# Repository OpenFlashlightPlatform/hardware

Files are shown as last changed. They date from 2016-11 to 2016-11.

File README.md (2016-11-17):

# Blue Sun OFP

The Blue Sun Open Flashlight Platform is an open source (both hardware and software)
attempt at creating a software-defined ultra-reliable high-performance flashlight.

This project was inspired by the AvE Midnight Sun project, and is intended to match
with the mechanicals developed there, both physically and in spirit. To that end,
a core set of specifications were identified:

 0. The project must be fun. This rule can be applied to override any subsequent
    rule.
 1. The design must be skookum. If in doubt as to the actual definition of "skookum"
    just go balls to the wall and hope the result is sufficiently epic.
 2. The platform should be capable of driving a diverse range of COBs at up to
    160W (40V / 4A). Ensure that in every aspect of the circuit, rule 1 is
    strongly enforced, so that excursions beyond 160W are tolerated and the
    circuit can dynamically detect and react to overload.
 3. The driver should have fine-grained current-mode control of the COB.
 4. The platform should operate from a 3s LiPo battery, and be capable of charging it
    from a 12V source. Naturally, transients, noise and polarity inversions on this
    source must be tolerated. Furthermore, all best practices for LiPo operation
    must be followed including UVLO, cell balancing and temperature monitoring.
 5. The platform should be accessible and open source at every possible level.
    To that end, it should be compatible out-of-the box with an Arduino IDE
    and programmable without any non-free tools, software or licenses.
 6. The circuit must be implemented in the spirit of Rule 1. Everything must be
    resistant to temperature, humidity, vibration, ESD, overvoltage, cell imbalance,
    and short circuit. The circuit must continue to function after being shaken
    in a container of salty boiling water mixed with conductive metal powder.
 7. Every net in the circuit, including internal nets and power supply rails,
    must pass IEC 61000-4-2 (25kV) and IEC 61004-4 (40A) ESD resistance tests.
 8. The firmware itself, both in source form and compiled form, must adhere to
    rule 1. In particular, wherever possible (in that it does not contradict rule
    5), the firmware should be MISRA C:2012 compliant.
 9. Every aspect of the project must be well documented. If the primary maintainer
    were to become unavailable, the community ought to be able to pick up and
    continue.

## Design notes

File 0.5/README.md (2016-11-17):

# Version 0.5

This is a prototype iteration, that has no battery charging features. It is so that I can work on the hardware and firmware in parallel.

It should in theory work for up to 160W COBs. I'll be testing that at a later stage.

The BOM is also available as a google doc here: https://goo.gl/zxzSkw

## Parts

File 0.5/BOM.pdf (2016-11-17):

Nothing fancy passives, any brand will do
Designator | Type | Notes
C1, C15, C17 | 100nF 25V 0603 X7R
C28 | 10uF 25V 0805 X5R | The pad is 0603, my bad
C16, C18 | 1uF 25V 0603 X7R
C2 | 10uF 6V3 0603 X5R
C3, C5, C7, C9, C12, C13, C21, C22, C23, C25, C26, C30 | 100nF 6V3 0603 X7R
C4, C6, C8, C10, C11, C14, C24, C27, C29 | 1uF 6V3 0603 X7R
R1, R2 | 5k6 0603 1%
R4, R6 | 1k 0603 1%
R5 | 82k 0603 1%
R7 | 15k 0603 1%
R8, R9 | 1k8 0603 1%
R10, R11, R12, R13 | 100R 0603 1%
R14, R15, R16 | 10k 0603 1%

Specific parts
Designator | Type | Manufacturer | MFG part no | Digikey part no | Price/100 USD | Qty | Notes
C19, C20 | 1mF 80V 10mm cap | CDE | 381LX102M080H012 | 338-3690-ND | 1.7 | 2
D1, D8 | SOT23 Schottky | Fairchild | BAT54C | BAT54CFSTR-ND | 0.09 | 2
D4, D5, D6, D7 | TVS diode 3.3V | Semtech | UCLAMP3301H.TCT | UCLAMP3301HCT-ND | 0.48 | 4
D2 | Big SlimDPAK schottky | Vishay | V35PWM12-M3/I | V35PWM12-M3/IGITR-ND | 0.88 | 1
J1 | SMT USB micro | Amphenol | 10118192-0001LF | 609-4613-1-ND | 0.3 | 1
L1 | 10uH 21A inductor | Wurth | 74435581000 | 732-4235-2-ND | 6.6 | 1
Q1, Q2 | Power MOSFET | NXP | PSMN034-100BS,118 | 568-9702-2-ND | 0.71 | 2
Q3, Q4 | Signal MOSFET | NXP | 2N7002P,215 | 568-5818-1-ND | 0.07 | 2
U1 | MCU | Atmel | ATSAMD21G18A-AUT | ATSAMD21G18A-AUTCT-ND | 4.15 | 1
U2 | LDO | ST Micro | LD1117S33CTR | 497-1241-1-ND | 0.25 | 1
U3, U4 | MOSFET driver | Microchip | MCP1416T-E/OT | MCP1416T-E/OTTR-ND | 0.49 | 2
U5, U6, U7 | Temp sensor | TI | LM73CIMK-1/NOPB | LM73CIMK-1/NOPBCT-ND | 1.48 | 3
U8, U9, U10 | Steering / TVS | NXP | IP4220CZ6,125 | 568-3529-2-ND | 0.23 | 3
R3 | Shunt resistor 15mR | TE Connectivity | RLP73V3AR015FTDF | A109674CT-ND | 0.25 | 1
D3 | The COB 13 klm (!) | CREE | CXA3590-0000-000N00CD0E3 | CXA3590-0000-000N00CD0E3-ND | 37.18 | 1 | Any <40V <4A COB is ok

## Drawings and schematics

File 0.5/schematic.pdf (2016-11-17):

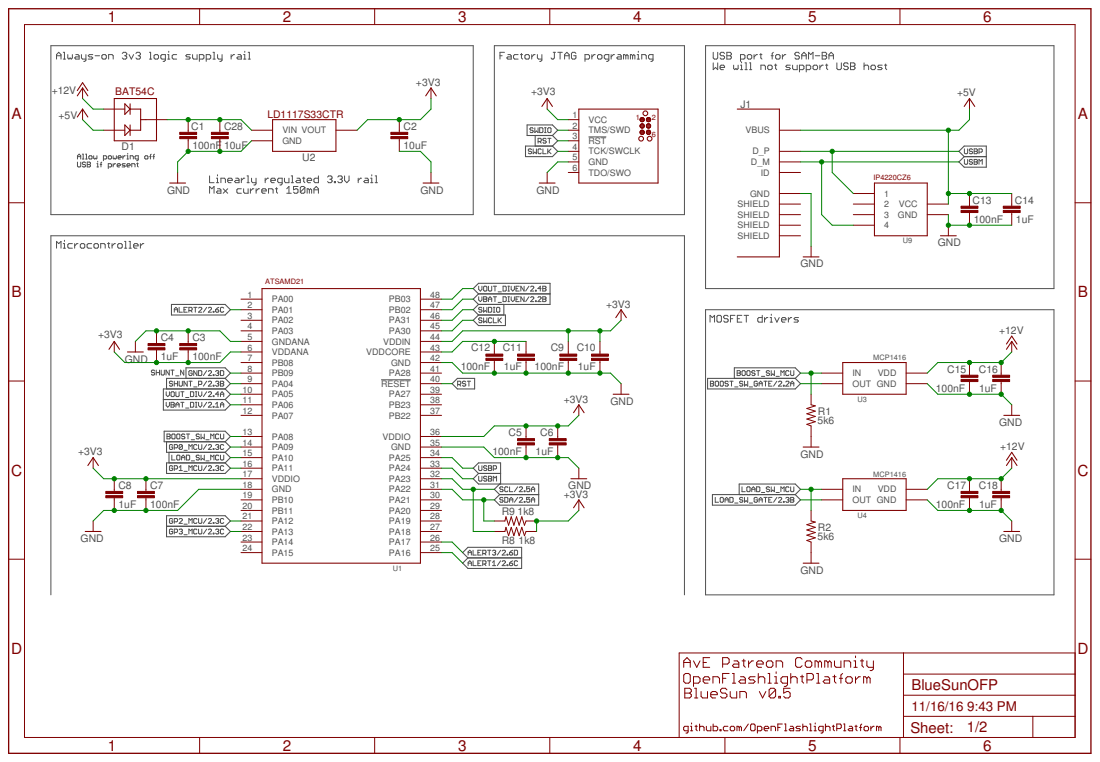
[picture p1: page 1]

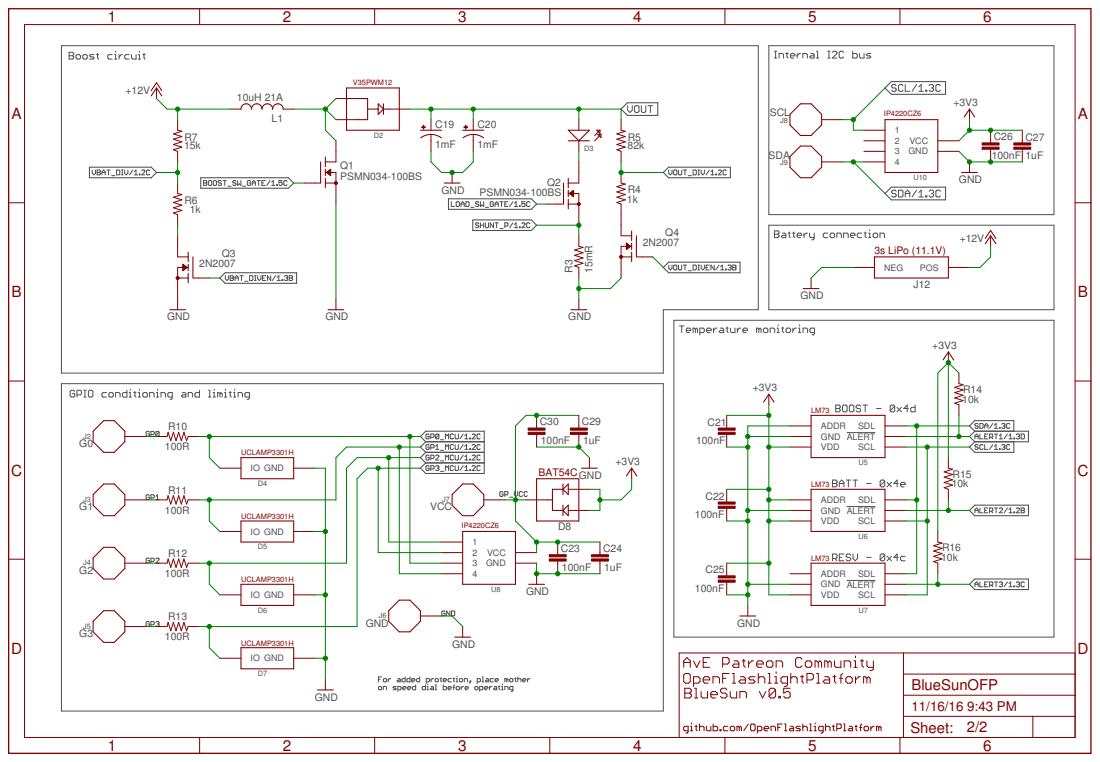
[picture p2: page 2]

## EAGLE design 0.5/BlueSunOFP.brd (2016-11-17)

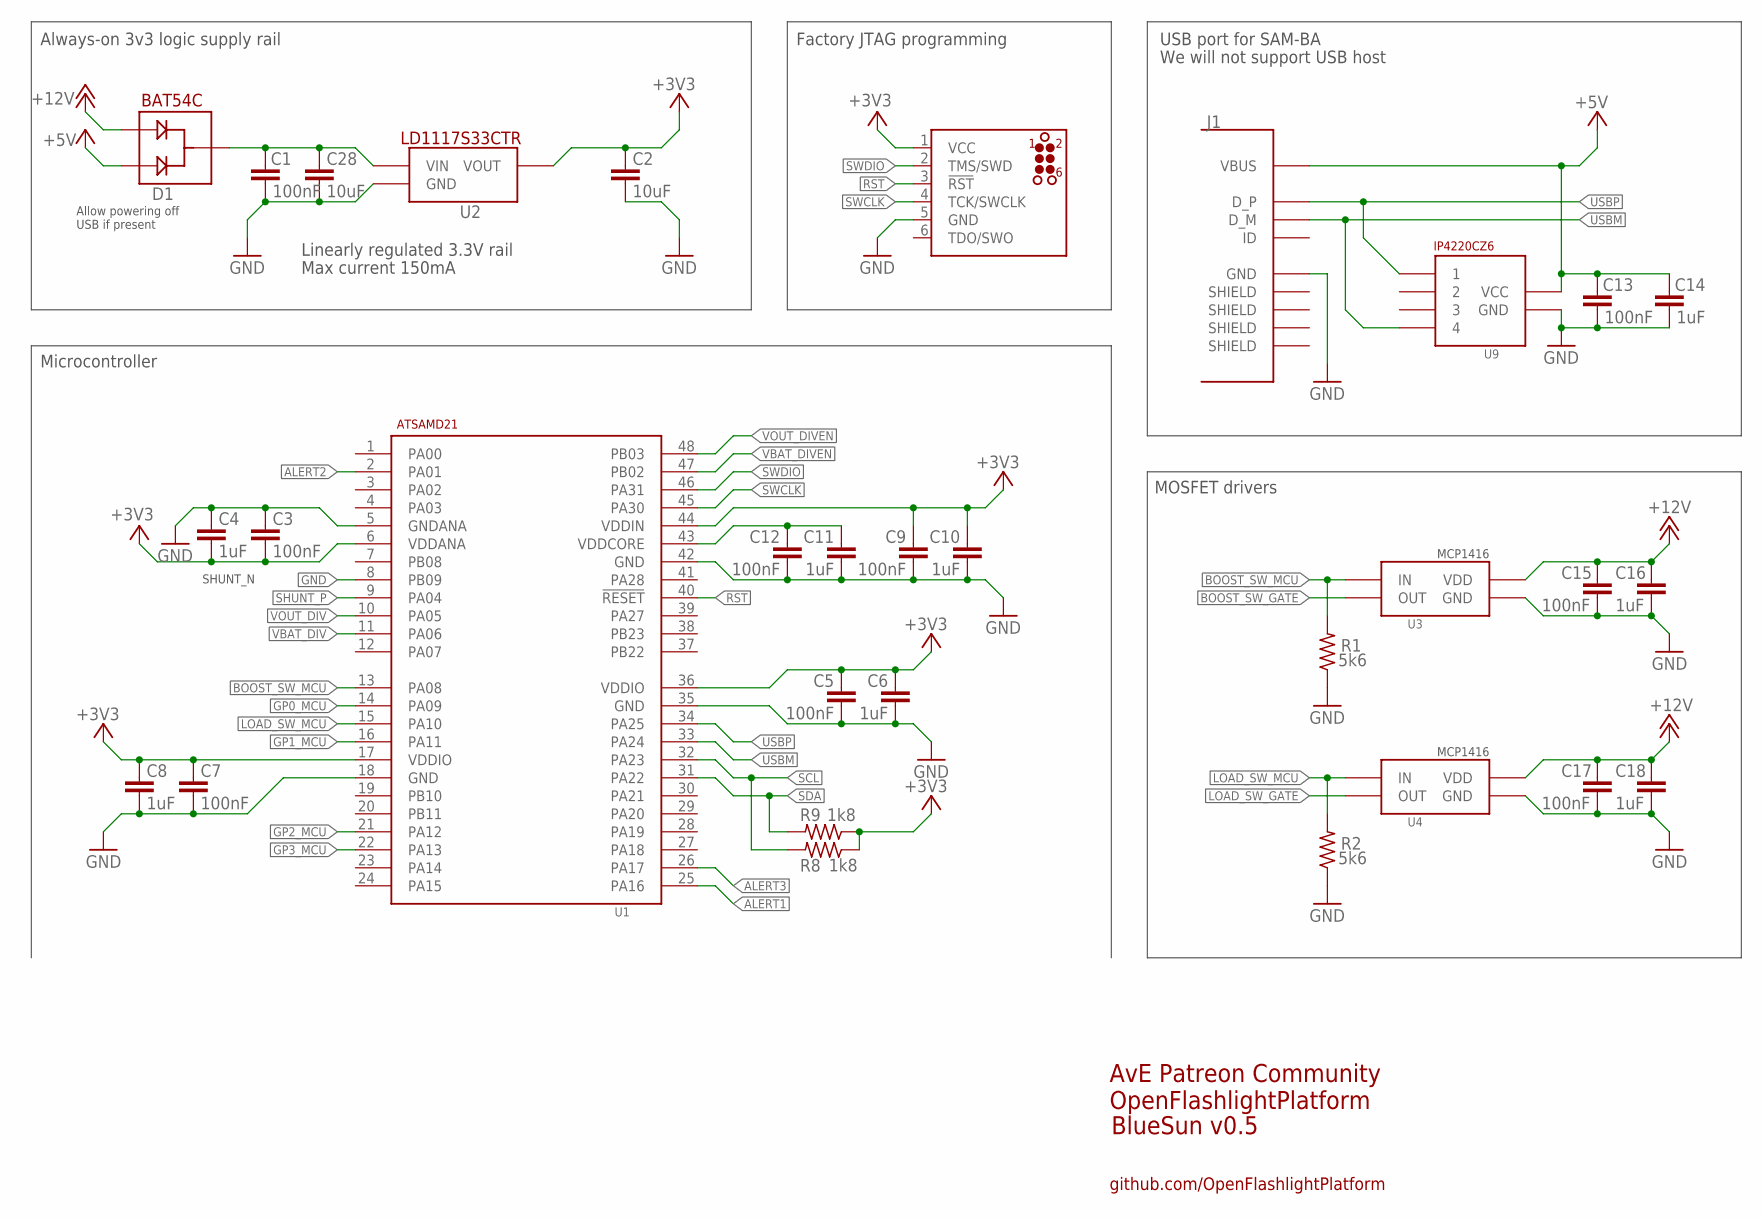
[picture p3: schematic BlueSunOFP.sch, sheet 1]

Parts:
C1, C13, C15, C17: 100nF; C0603K
C2, C28: 10uF; C0603K
C3, C5, C7, C9, C12: 100nF; C0402K
C4, C6, C8, C10, C11: 1uF; C0402K
C14, C16, C18: 1uF; C0603K
D1: BAT54C; SOT23
J1: USBSMT; USB_SMT
R1, R2: 5k6; R0603
R8, R9: 1k8; R0603
U1: SAMD21; TQFP48
U2: LD1117S33CTR_3V3_REG; SOT223
U3, U4: MCP1416; SOT23-5
U9: IP4220CZ6; SOT457
U$1: JLINK_CONNECT; TC2030-MCP-NL

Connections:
+3V3: C2.1, C3.2, C4.2, C5.1, C6.1, C7.1, C8.1, C9.1, C10.1, R8.1, R9.1, U1.6 (VDDANA), U1.17 (VDDIO), U1.36 (VDDIO), U1.44 (VDDIN), U2.2 (VOUT), U$1.1 (VCC); also elsewhere on the board
+5V: C13.1, C14.1, D1.2, J1.1VBUS (VBUS), U9.5 (VCC)
+12V: C15.1, C16.1, C17.1, C18.1, D1.1, U3.2 (VDD), U4.2 (VDD); also elsewhere on the board
ALERT1: U1.25 (PA16); also elsewhere on the board
ALERT2: U1.2 (PA01); also elsewhere on the board
ALERT3: U1.26 (PA17); also elsewhere on the board
BOOST_SW_GATE: U3.5 (OUT); also elsewhere on the board
BOOST_SW_MCU: R1.2, U1.13 (PA08), U3.3 (IN)
GND: C1.2, C2.2, C3.1, C4.1, C5.2, C6.2, C7.2, C8.2, C9.2, C10.2, C11.2, C12.2, C13.2, C14.2, C15.2, C16.2, C17.2, C18.2, C28.2, J1.5GND (GND), R1.1, R2.1, U1.5 (GNDANA), U1.8 (PB09), U1.18 (GND), U1.35 (GND), U1.42 (GND), U2.1 (GND), U3.4 (GND), U4.4 (GND), U9.2 (GND), U$1.5 (GND); also elsewhere on the board
GP0_MCU: U1.14 (PA09); also elsewhere on the board
GP1_MCU: U1.16 (PA11); also elsewhere on the board
GP2_MCU: U1.21 (PA12); also elsewhere on the board
GP3_MCU: U1.22 (PA13); also elsewhere on the board
LOAD_SW_GATE: U4.5 (OUT); also elsewhere on the board
LOAD_SW_MCU: R2.2, U1.15 (PA10), U4.3 (IN)
unnamed: C11.1, C12.1, U1.43 (VDDCORE)
unnamed: C1.1, C28.1, D1.3 (NEG), U2.3 (VIN)
RST: U1.40 (!RESET!), U$1.3 (!RST!)
SCL: R8.2, U1.32 (PA23); also elsewhere on the board
SDA: R9.2, U1.31 (PA22); also elsewhere on the board
SHUNT_P: U1.9 (PA04); also elsewhere on the board
SWCLK: U1.45 (PA30), U$1.4 (TCK/SWCLK)
SWDIO: U1.46 (PA31), U$1.2 (TMS/SWD)
USBM: J1.2D- (D_M), U1.33 (PA24), U9.6 (4)
USBP: J1.3D+ (D_P), U1.34 (PA25), U9.1
VBAT_DIV: U1.11 (PA06); also elsewhere on the board
VBAT_DIVEN: U1.47 (PB02); also elsewhere on the board
VOUT_DIV: U1.10 (PA05); also elsewhere on the board
VOUT_DIVEN: U1.48 (PB03); also elsewhere on the board

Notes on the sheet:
AvE Patreon Community
OpenFlashlightPlatform
BlueSun v0.5
github.com/OpenFlashlightPlatform
Linearly regulated 3.3V rail
Max current 150mA
Always-on 3v3 logic supply rail
Factory JTAG programming
Allow powering off USB if present
We will not support USB host
USB port for SAM-BA
MOSFET drivers
Microcontroller
SHUNT_N

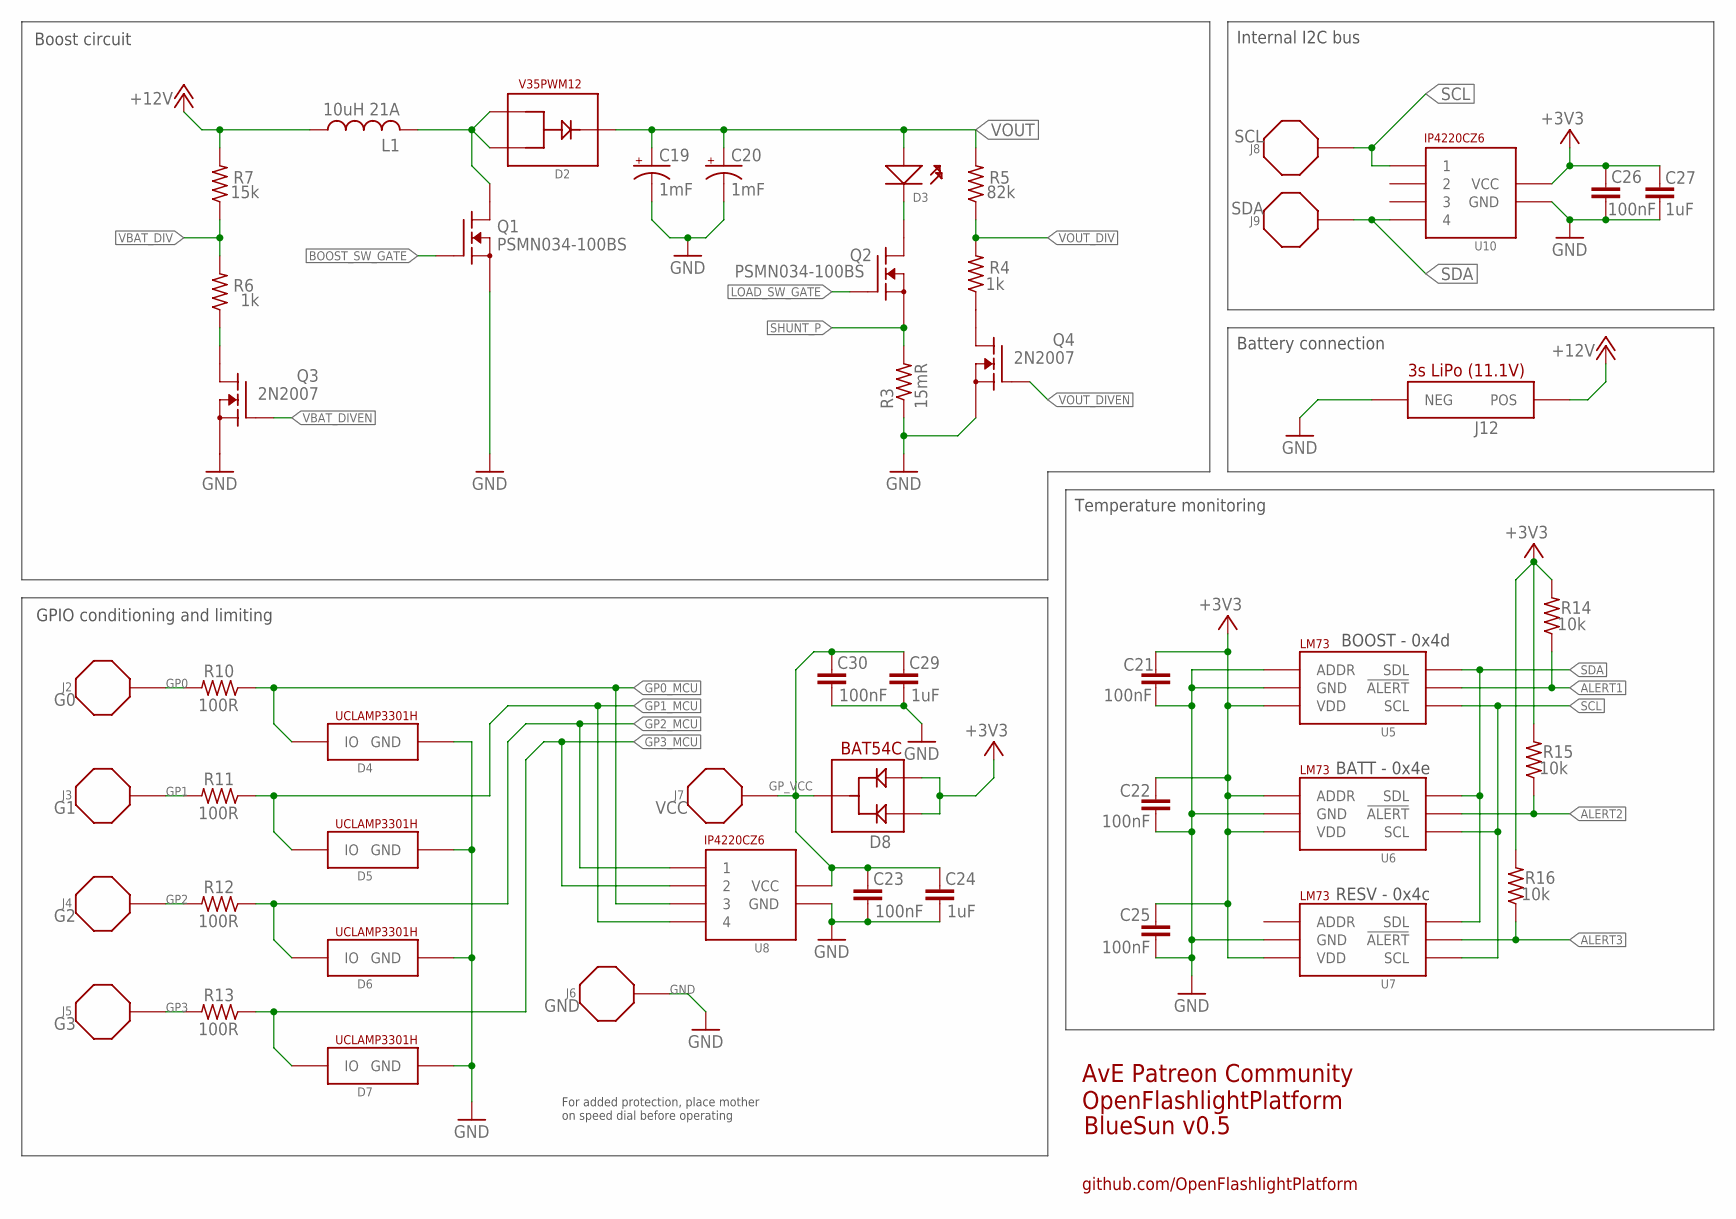
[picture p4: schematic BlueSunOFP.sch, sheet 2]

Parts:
C19, C20: 1mF; 10MMCAP
C21, C22, C23, C25, C26, C30: 100nF; C0603K
C24, C27, C29: 1uF; C0603K
D2: DIODE; SLIMPAK
D3: CREE_COB; CREE_WIRE_MOUNT
D4, D5, D6, D7: UCLAMP3301H; SOD523
D8: BAT54C; SOT23
J2: G0; EXT_PIN
J3: G1; EXT_PIN
J4: G2; EXT_PIN
J5: G3; EXT_PIN
J6: GND; EXT_PIN
J7: VCC; EXT_PIN
J8: SCL; EXT_PIN
J9: SDA; EXT_PIN
J12: BATTERY; CREE_WIRE_MOUNT
L1: 10uH 21A; INDUCTOR
Q1, Q2: PSMN034-100BS; D2PAK
Q3, Q4: 2N2007; SOT23
R3: 15mR; R2512
R4, R6: 1k; R0603
R5: 82k; R0603
R7: 15k; R0603
R10, R11, R12, R13: 100R; R0603
R14, R15, R16: 10k; R0603
U5, U6, U7: LM73; SOT23-6
U8, U10: IP4220CZ6; SOT457

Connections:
+3V3: C21.1, C22.1, C25.1, C26.1, C27.1, D8.1, D8.2, R14.2, R15.2, R16.2, U5.3 (VDD), U6.1 (ADDR), U6.3 (VDD), U7.3 (VDD), U10.5 (VCC); also elsewhere on the board
+12V: J12.POS, L1.P$1 (1), R7.2; also elsewhere on the board
ALERT1: R14.1, U5.5 (!ALERT!); also elsewhere on the board
ALERT2: R15.1, U6.5 (!ALERT!); also elsewhere on the board
ALERT3: R16.1, U7.5 (!ALERT!); also elsewhere on the board
BOOST_SW_GATE: Q1.1 (G); also elsewhere on the board
GND: C19.NEG (-), C20.NEG (-), C21.2, C22.2, C23.2, C24.2, C25.2, C26.2, C27.2, C29.2, C30.2, D4.NOLINE (GND), D5.NOLINE (GND), D6.NOLINE (GND), D7.NOLINE (GND), J6.P$1, J12.NEG, Q1.3 (S), Q3.2 (S), Q4.2 (S), R3.1, U5.1 (ADDR), U5.2 (GND), U6.2 (GND), U7.2 (GND), U8.2 (GND), U10.2 (GND); also elsewhere on the board
GP0: J2.P$1, R10.2
GP0_MCU: D4.LINE (IO), R10.1, U8.4 (3); also elsewhere on the board
GP1: J3.P$1, R11.2
GP1_MCU: D5.LINE (IO), R11.1, U8.6 (4); also elsewhere on the board
GP2: J4.P$1, R12.2
GP2_MCU: D6.LINE (IO), R12.1, U8.1; also elsewhere on the board
GP3: J5.P$1, R13.2
GP3_MCU: D7.LINE (IO), R13.1, U8.3 (2); also elsewhere on the board
GP_VCC: C23.1, C24.1, C29.1, C30.1, D8.3 (NEG), J7.P$1, U8.5 (VCC)
LOAD_SW_GATE: Q2.1 (G); also elsewhere on the board
unnamed: D2.1, D2.2, L1.P$2 (2), Q1.2 (D)
unnamed: D3.NEG, Q2.2 (D)
unnamed: Q3.3 (D), R6.1
unnamed: Q4.3 (D), R4.1
SCL: J8.P$1, U5.4 (SCL), U6.4 (SCL), U7.4 (SCL), U10.1; also elsewhere on the board
SDA: J9.P$1, U5.6 (SDL), U6.6 (SDL), U7.6 (SDL), U10.6 (4); also elsewhere on the board
SHUNT_P: Q2.3 (S), R3.2; also elsewhere on the board
VBAT_DIV: R6.2, R7.1; also elsewhere on the board
VBAT_DIVEN: Q3.1 (G); also elsewhere on the board
VOUT: C19.POS (+), C20.POS (+), D2.K, D3.POS, R5.2
VOUT_DIV: R4.2, R5.1; also elsewhere on the board
VOUT_DIVEN: Q4.1 (G); also elsewhere on the board

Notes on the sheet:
AvE Patreon Community
OpenFlashlightPlatform
BlueSun v0.5
github.com/OpenFlashlightPlatform
For added protection, place mother on speed dial before operating
GPIO conditioning and limiting
Boost circuit
BOOST - 0x4d
BATT - 0x4e
RESV - 0x4c
Temperature monitoring
Internal I2C bus
Battery connection

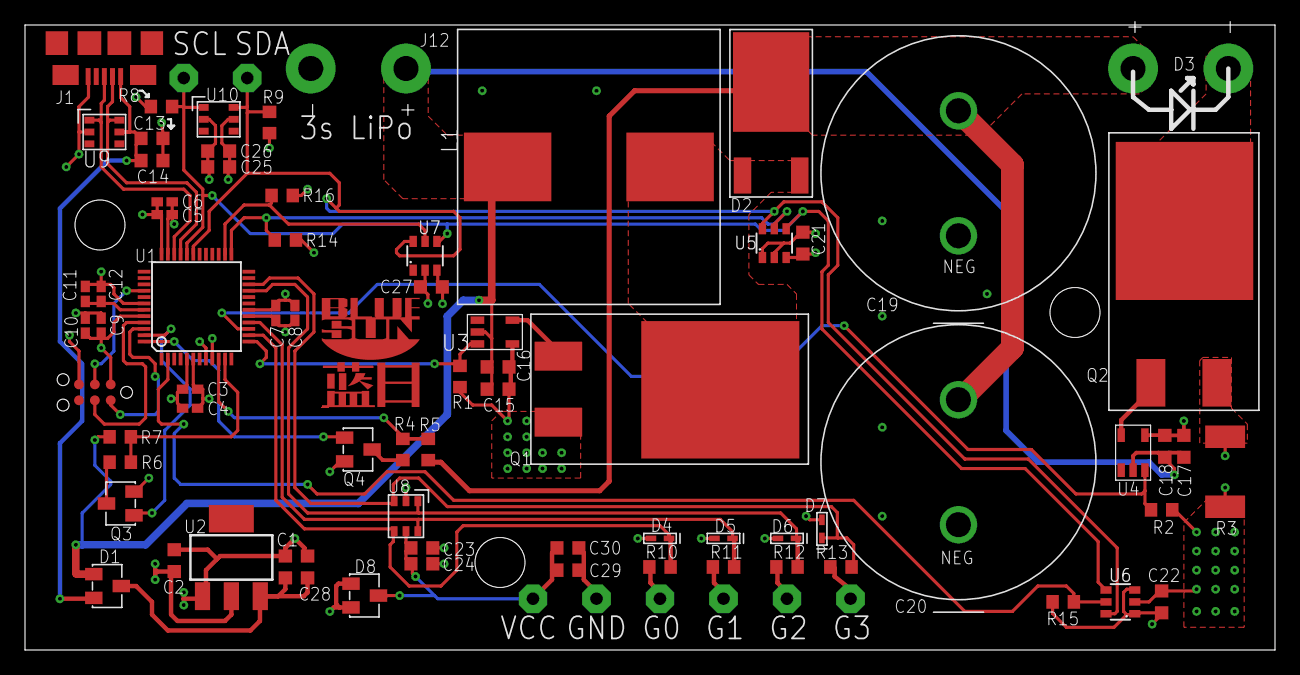
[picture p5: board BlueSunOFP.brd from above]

Board: 4 copper layers, 100.0 x 50.0 mm, 80 parts (0 on the bottom side), 39 nets.

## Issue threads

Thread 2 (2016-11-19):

low side switching dividers no bueno

immesys, 2016-11-19:
facepalm

In the design, there are voltage dividers to measure vbatt (max 16V)  and vout (max 80V) within the bangap ADC range (0 to 1V). Because I was concerned about quiescent current, I put low side mosfets there to enable switching the dividers off. This was stupid, because if you disconnect ground, the divider is no longer dividing and we have high voltage on the MCU pin (high impedance, yes, but high voltage). It may be that the MCU steering diodes will protect against frying the input, but I doubt that they can handle 80V or 1mA (the input impedance is 80k).

So for this version, we must not turn the dividers off. I'll probably short drain-source when I solder it.

We need to rethink how we do this as P-channel would be difficult to switch too, unless we use low side switching on the gate of the P-channel that has a pullup. How do other people solve this problem? Perhaps an opto-isolated mosfet on the high side will work.

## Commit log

2016-11-17 Initial version
    [BlueSunOFP.brd, BlueSunOFP.sch]
2016-11-17 Add BOM and pdf schematic
    [BOM.xlsx]

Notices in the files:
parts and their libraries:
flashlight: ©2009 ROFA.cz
